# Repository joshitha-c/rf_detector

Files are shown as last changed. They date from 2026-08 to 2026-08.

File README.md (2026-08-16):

#  Wi-Fi and Bluetooth Signal Tracker

A portable, custom-built RF signal scanner and power detector designed for knowing wireless signals, measuring signal strength and can be used to be safe. Built around the ESP32-C3 microcontroller and the AD8318 logarithmic RF power detector, this device provides real-time visual readings alongside multi-sensory (visual, audible, and tactile) feedback.

---

## Key Features

* **Core Processor:** ESP32-C3-WROOM-02 handling Wi-Fi/Bluetooth scanning, logic, and native USB programming.
* **RF Detection Engine:** AD8318 RF Power Detector module paired with an SMA antenna connector for precise wideband signal measurement.
* **Display:** 2.4-inch SPI TFT LCD (ILI9341) for live graphical signal readouts.
* **UI Controls:** EC11 Rotary Encoder with an integrated push button, expanded over I2C using a PCA9536 GPIO expander to free up MCU pins.
* **Multi-Sensory Alerts:**
  * **RGB LED:** Addressable WS2812B LED (Red = Strong, Yellow = Medium, Green = Weak).
  * **Audio:** Active piezo buzzer providing frequency-pitched sound feedback.
  * **Haptics:** Coin vibration motor driven by a low-side MOSFET.
  * **Flashlight:** Integrated 1W white LED powered directly from the battery line.
* **Power & Charging:**
  * Powered by a standard 3.7V Li-Po/Li-ion single cell.
  * Onboard USB-C port backed by an MCP73831 charger IC (set to 500mA).
  * AP2112K-3.3 (600mA) ultra-low-dropout regulator for stable logic power.
  * Dedicated slide switch for physical battery cut-off.
  * Resistor voltage divider network for monitoring battery percentage in real time.

---
## Bill of Materials (BOM) Summary

| Category | Component | Description / Footprint |
| :--- | :--- | :--- |
| **Microcontroller** | ESP32-C3-WROOM-02 | Main Wi-Fi/BLE MCU (`RF_Module:ESP32-C3-WROOM-02`) |
| **RF Detector** | AD8318 / U.FL Jack | RF Power Detector (`CSP-16` / `U.FL-R-SMT-1`) |
| **Power Management** | MCP73831 & AP2112K-3.3 | Li-Po Charger & 600mA LDO Regulator (`DFN-8` / `SOT-23-5`) |
| **Display** | 2.4" ILI9341 TFT | 320x240 SPI Screen Module Header (`1x14 2.54mm`) |
| **I2C Expander** | PCA9536D | 4-bit GPIO Expander for Encoder (`SOIC-8`) |
| **Input** | EC11 Encoder | Rotary Encoder with Switch (`RotaryEncoder_EC11E`) |
| **Lighting** | WS2812B & 1W White LED | RGB Status LED & Flashlight (`5050 SMD` / `3535 SMD`) |
| **Drivers** | AO3400A / 2N7002 | N-Channel MOSFETs (`SOT-23`) |
| **Passives** | Resistors / Capacitors | Standard 0805 SMD footprints |

## Tools Used

* **Design Software:** KiCad)
## schematics:

## pcb:


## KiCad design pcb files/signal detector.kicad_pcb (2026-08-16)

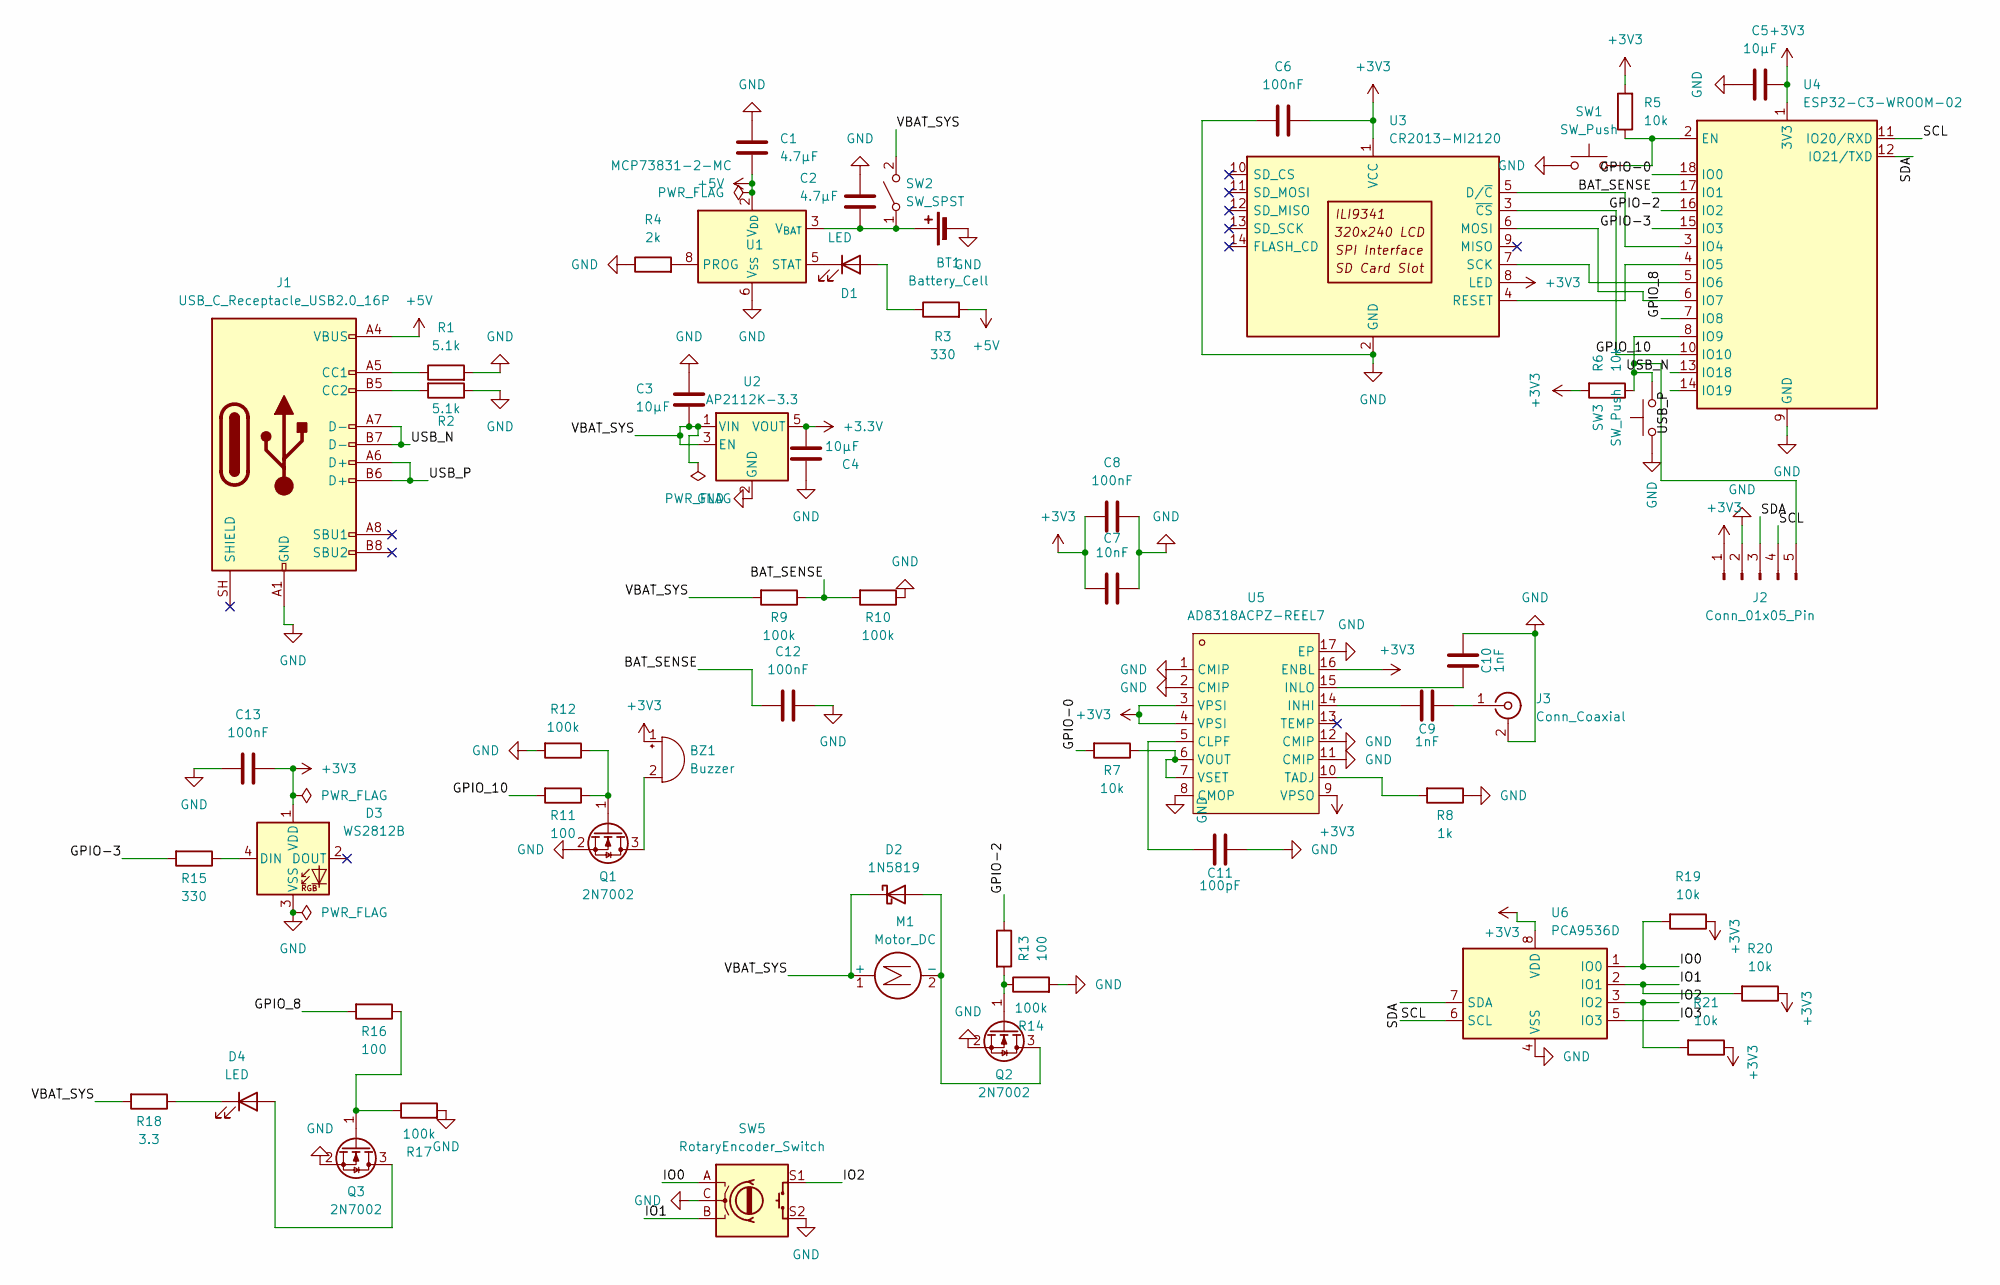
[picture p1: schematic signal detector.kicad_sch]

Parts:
BT1: Battery_Cell; JST_PH_B2B-PH-K_1x02_P2.00mm_Vertical
BZ1: Buzzer; Buzzer_12x9.5RM7.6
C1, C2: 4.7µF; C_0805_2012Metric
C3, C4, C5: 10µF; C_0805_2012Metric
C6, C8, C12, C13: 100nF; C_0805_2012Metric
C7: 10nF; C_0805_2012Metric
C9, C10: 1nF; C_0805_2012Metric
C11: 100pF; C_0805_2012Metric
D1: LED; LED_0805_2012Metric
D2: 1N5819; D_DO-41_SOD81_P10.16mm_Horizontal
D3: WS2812B; LED_WS2812B_PLCC4_5.0x5.0mm_P3.2mm
D4: LED; LED_D3.0mm
J1: USB_C_Receptacle_USB2.0_16P; USB_C_Receptacle_HRO_TYPE-C-31-M-12
J2: Conn_01x05_Pin; PinHeader_1x05_P2.54mm_Vertical
J3: Conn_Coaxial; U.FL_Hirose_U.FL-R-SMT-1_Vertical
M1: Motor_DC; R_0805_2012Metric
Q1, Q2, Q3: 2N7002; SOT-23
R1, R2: 5.1k; R_0805_2012Metric
R3, R15: 330; R_0805_2012Metric
R4: 2k; R_0805_2012Metric
R5, R6, R7, R19, R20, R21: 10k; R_0805_2012Metric
R8: 1k; R_0805_2012Metric
R9, R10, R12, R14, R17: 100k; R_0805_2012Metric
R11, R13, R16: 100; R_0805_2012Metric
R18: 3.3; R_0805_2012Metric
SW1, SW3: SW_Push; SW_SPST_PTS645Sx43SMTR92
SW2: SW_SPST; SW_SPST_CK_KMS2xxG
SW5: RotaryEncoder_Switch; RotaryEncoder_Alps_EC11E-Switch_Vertical_H20mm
U1: MCP73831-2-MC; DFN-8-1EP_3x2mm_P0.5mm_EP1.7x1.4mm
U2: AP2112K-3.3; SOT-23-5
U3: CR2013-MI2120
U4: ESP32-C3-WROOM-02
U5: AD8318ACPZ-REEL7; LFCSP-16_L4.0-W4.0-P0.65-BL-EP2.2; MPN AD8318ACPZ-REEL7; LCSC Part C578694
U6: PCA9536D; SOIC-8_3.9x4.9mm_P1.27mm

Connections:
+3.3V: C4.1, U2.5 (VOUT)
+3V3: BZ1.1 (+), C5.1, C6.1, C7.2, C8.2, C13.1, D3.1 (VDD), J2.1, R5.2, R6.2, R19.1, R20.1, R21.1, U3.1 (VCC), U3.8 (LED), U4.1 (3V3), U5.3 (VPSI), U5.4 (VPSI), U5.9 (VPSO), U5.16 (ENBL), U6.8 (VDD)
+5V: C1.1, J1.A4 (VBUS), J1.A9 (VBUS), J1.B4 (VBUS), J1.B9 (VBUS), R3.2, U1.1 (V_{DD}), U1.2 (V_{DD})
/BAT_SENSE: C12.2, R9.1, R10.2, U4.17 (IO1)
/GPIO-0: R7.2, U4.18 (IO0)
/GPIO-2: R13.1, U4.16 (IO2)
/GPIO-3: R15.2, U4.15 (IO3)
/GPIO_8: R16.2, U4.7 (IO8)
/GPIO_10: R11.2, U3.3 (~CS), U4.10 (IO10)
/IO0: R19.2, SW5.A, U6.1 (IO0)
/IO1: R20.2, SW5.B, U6.2 (IO1)
/IO2: R21.2, SW5.S1, U6.3 (IO2)
/IO3: U6.5 (IO3)
/SCL: J2.4, U4.11 (IO20/RXD), U6.6 (SCL)
/SDA: J2.3, U4.12 (IO21/TXD), U6.7 (SDA)
/USB_N: J1.A7 (D-), J1.B7 (D-), U4.13 (IO18)
/USB_P: J1.A6 (D+), J1.B6 (D+), U4.14 (IO19)
/VBAT_SYS: C3.1, D2.1 (K), M1.1 (+), R9.2, R18.2, SW2.2 (B), U2.1 (VIN), U2.3 (EN)
GND: BT1.2 (-), C1.2, C2.2, C3.2, C4.2, C5.2, C6.2, C7.1, C8.1, C10.1, C11.1, C12.1, C13.2, D3.3 (VSS), J1.A1 (GND), J1.A12 (GND), J1.B1 (GND), J1.B12 (GND), J2.2, J3.2 (Ext), Q1.2 (S), Q2.2 (S), Q3.2 (S), R1.2, R2.1, R4.1, R8.1, R10.1, R12.2, R14.2, R17.2, SW1.1, SW3.1, SW5.C, SW5.S2, U1.6 (V_{SS}), U2.2 (GND), U3.2 (GND), U4.9 (GND), U4.19 (GND), U5.1 (CMIP), U5.2 (CMIP), U5.8 (CMOP), U5.11 (CMIP), U5.12 (CMIP), U5.17 (EP), U6.4 (VSS)
unnamed: BT1.1 (+), C2.1, SW2.1 (A), U1.3 (V_{BAT}), U1.4 (V_{BAT})
unnamed: BZ1.2 (-), Q1.3 (D)
unnamed: D1.2 (A), R3.1
unnamed: D1.1 (K), U1.5 (STAT)
unnamed: D2.2 (A), M1.2 (-), Q2.3 (D)
unnamed: D3.4 (DIN), R15.1
unnamed: D4.2 (A), Q3.3 (D)
unnamed: D4.1 (K), R18.1
unnamed: J1.A5 (CC1), R1.1
unnamed: J1.B5 (CC2), R2.2
unnamed: J2.5, R6.1, SW3.2, U4.8 (IO9)
unnamed: C9.1, J3.1 (In)
unnamed: Q1.1 (G), R11.1, R12.1
unnamed: Q2.1 (G), R13.2, R14.1
unnamed: Q3.1 (G), R16.1, R17.1
unnamed: R4.2, U1.8 (PROG)
unnamed: U3.5 (D/~C), U4.3 (IO4)
unnamed: U3.6 (MOSI), U4.6 (IO7)
unnamed: U3.4 (RESET), U4.4 (IO5)
unnamed: U3.7 (SCK), U4.5 (IO6)
unnamed: R5.1, SW1.2, U4.2 (EN)
unnamed: C11.2, U5.5 (CLPF)
unnamed: C9.2, U5.14 (INHI)
unnamed: C10.2, U5.15 (INLO)
unnamed: R8.2, U5.10 (TADJ)
unnamed: R7.1, U5.6 (VOUT), U5.7 (VSET)

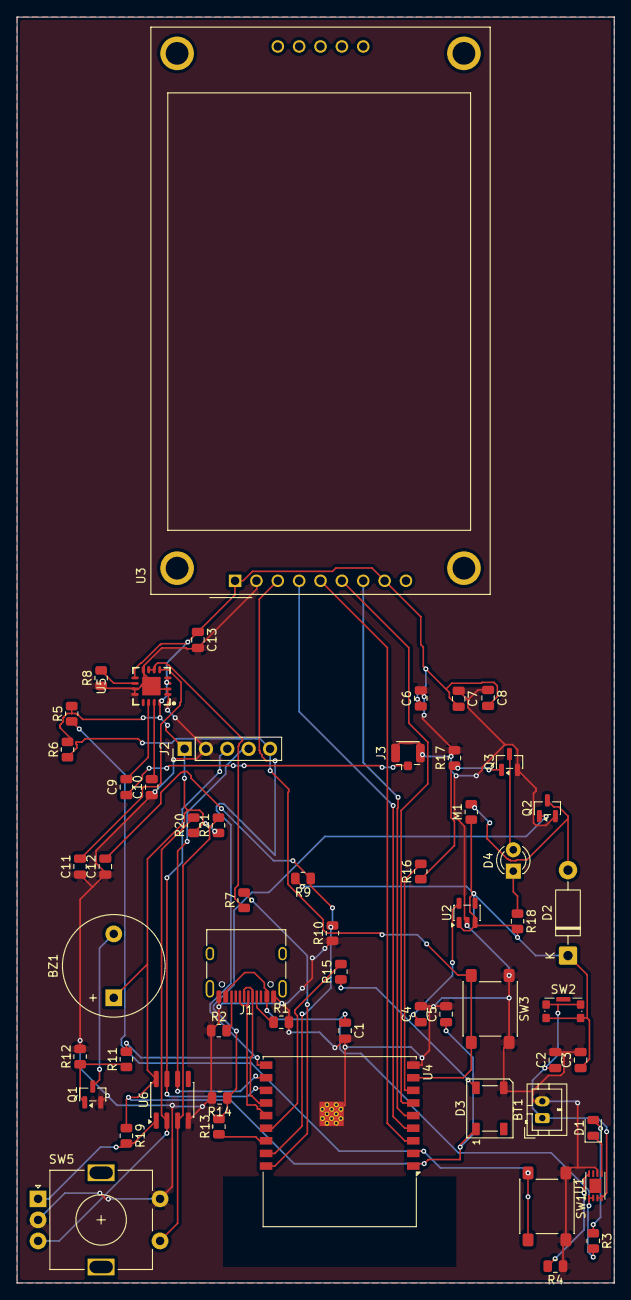
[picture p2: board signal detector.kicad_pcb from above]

Board: 2 copper layers, 71.0 x 150.5 mm, 57 parts (0 on the bottom side), 44 nets.

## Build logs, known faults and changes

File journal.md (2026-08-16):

# date:07/8
# time spent:1.5hr
## description:
To plan my custom handheld Wi-Fi and Bluetooth signal tracker, I researched open-source RF detectors and electronics suppliers to select components that balance precision, portability, and performance. For the brain, I chose the compact **ESP32-C3** microcontroller to handle wireless scanning and system logic, pairing it with an **AD8318 RF power detector** module and an **SMA antenna** for accurate signal measurement. I paired this with a vibrant **2.4" SPI TFT display** for real-time signal readout, seamlessly navigated using an **EC11 rotary encoder** with an integrated push button. The device is powered by a rechargeable **3.7V Li-ion battery**, featuring a **USB-C port** backed by an **MCP73831 charger IC** and a **600mA AP2112K 3.3V LDO** to keep power steady during heavy wireless bursts. For instant feedback, I incorporated a multi-sensory alert system with a **WS2812B RGB LED**, an **active buzzer**, and a **coin vibration motor**, plus a **1W white LED flashlight** and battery voltage monitoring for practical field use.
# images:


------
# date:07/8
# time spent:1.25hr
## description:
First i started gathering the footprints of each part and then i had started with the usb c receptable port for the part and then connected them with the resistor.
ANd then the MCP73831 charger topping off your 3.7V battery at 500 ma while lighting up a status LED while it charges.
then i starteD placed a main power switch right after the battery so you can flip the tracker on or off whenever you want, even while it's plugged in and charging.
That battery power goes into the AP2112K regulator, which tames the fluctuating battery voltage 3.0V into a super stable 3.3V parts.The next part is the Esp module which is the main part of the device.
# images:




------
# date:08/8
# time spent:1.5hr
## description:
First i started searching for the displays in online and then i had found the ili9341 display which suits my design and then i need to add the main part of the project that is the esp microcontroller that i had taken the model:ESP32-C3-WROOM-02 and then i had connected the microntroller with display and then i had connected USB data lines (D- on gpio18 and D+ on gpio19) for direct USB-C programming and added a 1x5 pin header as a backup UART debugging interface.ANd then connected the gpio7,gpio8 to the usb c port .
# images:



------
# date:08/8
# time spent:1.25hr
## description:
I had started the rf adapter part in which first i had started checking the docs of the AD8318ACPZ-REEL7 and i found how to use these connections and then connected it with the j3 coaxial jack and then i connected the rf adapter to the esp-s3 module.
# images:



------
# date:08/8
# time spent:1.5hr
## description:
I had started with the implemententaion with a battery voltage monitor using a symmetric voltage divider formed by two 100k resistors,this safely halves the variable battery voltage and then i also added a buzzer to the devicce so that tehre would be some sound when we feel the frequency,and then i connected the buzzer with the esp s3 controller,and then i had checked about thevibration motor which provides some vibration when there is a signal and it links like the same as the buzzer and then i connected it with the esp-s3 controller and then i had added a schotkeyy devicce for the circuit
# images:




------
# date:08/8
# time spent:1.75hr
## description:
I had started building the led WS2812Brgb in the circuit for the knowing the status in for the signal detector (red-strong,yellow-normal,green-weak),and then i also added in the an led flashlight in the circuit and then Powered directly from VBAT_SYS and then added 100ohm pull-down holds the MOSFET.Then i added an rotatory encoder which needed gpio pins ,but all were ussed in the esp-s3 module so i have added and extender to the sda,scl line and then connected it to the rotatory encoder to it.
# images:






------
# date:08/8
# time spent:0.75hr
## description:
First i had started running the erc ,in that i had many errors which were nearly 20 and then i had to go through each one and then fix them ,many were regarding the no connections in the pins of the parts and then some errors were regarding the classic kicad power output ,so i added each pwr_flag to the points where there was a problem
# images:



------
# date:08/8
# time spent:1.25hr
## description:
I had started assigning footprints for each i had checked the each part and its assigned footprints in the lscs number in the mouser website and first i added all the footprints and then i had found many errors while updating ,i fixed the each one by changing it into newer parts and then at last i had fixed all the problems,and i had tried to fix the warnings,bu found out that they were common,so i left them.
# images:






------
# date:09/8
# time spent:1hr
## description:
I had started the arrangment off the pieces in the devicces it was very difficult because there were many small resistors which was very difficult to make them in a enclosure but the bigger pieces were easy to move as they were less and then i had done the edge cuts for the device
# images:





------
# date:09/8
# time spent:2.5hr
## description:
I had started the routing work which was very difficult to complete,i had completed the routing of the pcb and i have completed only 70% the rest was bit difficult so i will complete it later.
# images:


------
# date:09/8
# time spent:0.75hr
## description:
The hardest part of connecting wires has been completed and this part was bit difficult as it contains all about the junnctions and the via points between each layers ,now i should run the erc and see if there wwere any errors
# images:



------
# date:09/8
# time spent:0.75hr
## description:
I had ran the design rule checker and i had found ou that there were 17 errors in which many wires were overlapping so i had rerouted the wiring and fixed all the errors ans some errors were regarding mounting holes which were too fixed and i had ignored the warnings,and the pcb was good in the 3d view
# images:





------
# date:09/8
# time spent:0.5hr
## description:
I had completed the readme and also i had exported the gerber files and also exported the cad files in the repo and then i had zipped the simulator and released it in the github repo.

------
# date:16/8
# time spent:1.25hr
## description:
I had changed the pcb layout and firstly ichanged the differential pairs for data wiring in the schematic and the pcb and then i had changed the disctance from the keep out zone so that there would be no signal issue and then i had figured out how to add the ground planes on both sides and added them and then madde alll the resistors to the same model.
# images:



------
# date:16/8
# time spent:0.5hr
## description:
I had rechecked the drc so that there would be no issue and i had fixed all the errors in the drc which were arround 30 and many of them were regarding traces issue and i fixed them all.
# images:



------
# Total hrs:18.00hrs
## Tech: kicad
